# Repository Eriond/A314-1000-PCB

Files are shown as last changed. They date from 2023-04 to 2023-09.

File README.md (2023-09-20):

# A314-1000-PCB
A314 board for the A1000's front memory expansion bay

<p>This is the Amiga 1000 version of [the A314](https://github.com/niklasekstrom/a314), designed to fit in the front expansion bay of the iconic computer.<br>
It is built using readily available components and has been designed with the DIY builder in mind (ie. no BGA chips, and reasonably large components with external leads)</p>
<p>It is a 1:1 replacement for the A1050 C= memory expansion, and will provide 256kB of chipRAM regardless if the RPiZ module is present.<br>
The board has room for an optional RTC chip which can provide time and date to the RPiZ via an I2C bus. This bus has also been made available via solderpads and is accessible from both sides of the PCB. It can be useful if you'd like to add other peripherals, like RGB lights or an OLED display for instance.</p>

For more information on how to bring this hardware to life, please check out Niklas repository at [https://github.com/niklasekstrom/a314-1000-gateware](https://github.com/niklasekstrom/a314-1000-gateware)

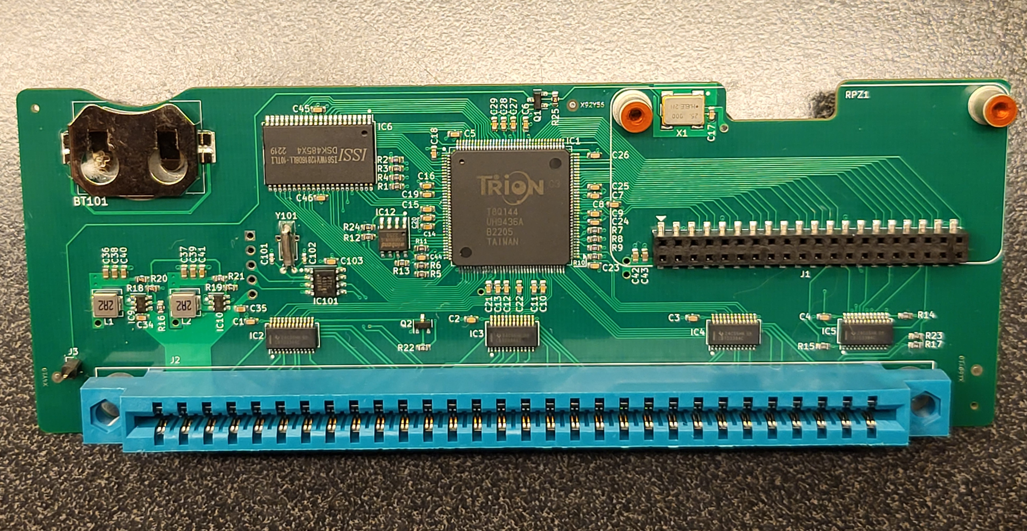
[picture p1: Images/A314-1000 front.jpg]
PCB


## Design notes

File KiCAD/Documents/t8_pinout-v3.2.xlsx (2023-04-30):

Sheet: T8F49
© 2020 |  |  | v13
Bank Number | Pin Name | Configuration Function | FBGA49
- | VCC |  | C4
- | VCC |  | D5
- | VCC |  | -
- | VCC |  | -
- | VCC |  | -
- | GND |  | A2 | Legend
- | GND |  | A6 |  | Bank 1A pins
- | GND |  | B1 |  | Bank 1B pins
- | GND |  | C1 |  | Bank 1C pins
- | GND |  | C5 |  | Bank 2A pins
- | GND |  | D4 |  | bank 2B pins
- | GND |  | E7
- | GND |  | -
- | GND |  | -
- | GND |  | -
BANK1A | CDONE | CDONE | F4
BANK1A | CRESET_N | CRESET_N | G4
BANK1A | GPIOL_00 |  | -
BANK1A | GPIOL_01_SS_N | SS_N | G3
BANK1A | GPIOL_02_CCK | CCK | F3
BANK1A | GPIOL_03_CDI4 | CDI4 | G2
BANK1A | GPIOL_04_CDI0 | CDI0 | F2
BANK1A | GPIOL_05_CDI5 | CDI5 | G1
BANK1A | GPIOL_06_CDI1 | CDI1 | F1
BANK1A | GPIOL_07_CDI6 | CDI6 | E3
BANK1A | GPIOL_08 |  | -
BANK1A | GPIOL_09_CDI2 | CDI2 | E2
BANK1A | GPIOL_10_CDI7 | CDI7 | E1
BANK1A | GPIOL_11_CDI3 | CDI3 | D2
BANK1A | GPIOL_12_CTRL0 |  | C2
BANK1A | GPIOL_13_CTRL1 |  | D3
BANK1A | GPIOL_14_CLK0 |  | C3
BANK1A | GPIOL_15_CLK1 |  | -
BANK1A | VCCIO1A |  | D1
BANK1B | GPIOL_16_CLK2 |  | B3
BANK1B | GPIOL_17_CLK3 |  | -
BANK1B | GPIOL_18_CTRL2 |  | A3
BANK1B | GPIOL_19_CTRL3 |  | -
BANK1B | GPIOL_20_PLLIN |  | B4
BANK1B | GPIOL_21_NSTATUS | NSTATUS | A4
BANK1B | TCK |  | -
BANK1B | TDI |  | -
BANK1B | TDO |  | -
BANK1B | TMS |  | -
BANK1B | VCCIO1B |  | B2
BANK1C | VCCA_PLL |  | A1
BANK2A | GPIOR_00 |  | -
BANK2A | GPIOR_01 |  | -
BANK2A | GPIOR_02_RESERVED_OUT | RESERVED_OUT | B5
BANK2A | GPIOR_03 |  | -
BANK2A | GPIOR_04 |  | -
BANK2A | GPIOR_05 |  | A5
BANK2A | GPIOR_06 |  | -
BANK2A | GPIOR_07 |  | A7
BANK2A | GPIOR_08 |  | -
BANK2A | GPIOR_09 |  | -
BANK2A | GPIOR_10 |  | B7
BANK2A | GPIOR_11 |  | -
BANK2A | GPIOR_12 |  | -
BANK2A | GPIOR_13 |  | C6
BANK2A | GPIOR_14 |  | -
BANK2A | GPIOR_15_CBUS0 | CBUS0 | D6
BANK2A | GPIOR_16_CTRL7_CBUS1 | CBUS1 | C7
BANK2A | GPIOR_17_CTRL6_CBUS2 | CBUS2 | D7
BANK2A | GPIOR_18_CLK7 |  | -
BANK2A | GPIOR_19_CLK6 |  | E6
BANK2A | VCCIO2A |  | B6
BANK2B | GPIOR_20_CLK5 |  | -
BANK2B | GPIOR_21_CLK4_CBSEL1 | CBSEL1 | E4
BANK2B | GPIOR_22_CTRL5 |  | -
BANK2B | GPIOR_23_CTRL4 |  | E5
BANK2B | GPIOR_24 |  | F5
BANK2B | GPIOR_25 |  | -
BANK2B | GPIOR_26_CBSEL0 | CBSEL0 | F6
BANK2B | GPIOR_27 |  | -
BANK2B | GPIOR_28 |  | -
BANK2B | GPIOR_29 |  | -
BANK2B | GPIOR_30 |  | -
BANK2B | GPIOR_31 |  | -
BANK2B | GPIOR_32 |  | -
BANK2B | GPIOR_34_CSI | CSI | G5
BANK2B | GPIOR_35_CSO | CSO | G6
BANK2B | GPIOR_36 |  | -
BANK2B | GPIOR_37_TEST_N | TEST_N | G7
BANK2B | VCCIO2B |  | F7

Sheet: T8F81
© 2020 |  |  | v13
Bank Number | Pin Name | Configuration Function | FBGA81
- | VCC |  | D4
- | VCC |  | E5
- | VCC |  | F2
- | VCC |  | F9
- | VCC |  | C1
- | GND |  | A2 | Legend
- | GND |  | B1 |  | Bank 1A pins
- | GND |  | B7 |  | Bank 1B pins
- | GND |  | D1 |  | Bank 1C pins
- | GND |  | D5 |  | Bank 2A pins
- | GND |  | E4 |  | bank 2B pins
- | GND |  | E9
- | GND |  | G2
- | GND |  | G7
- | GND |  | H1
BANK1A | CDONE | CDONE | H5
BANK1A | CRESET_N | CRESET_N | J5
BANK1A | GPIOL_00 |  | G5
BANK1A | GPIOL_01_SS_N | SS_N | J4
BANK1A | GPIOL_02_CCK | CCK | H4
BANK1A | GPIOL_03_CDI4 | CDI4 | G4
BANK1A | GPIOL_04_CDI0 | CDI0 | F4
BANK1A | GPIOL_05_CDI5 | CDI5 | J3
BANK1A | GPIOL_06_CDI1 | CDI1 | H3
BANK1A | GPIOL_07_CDI6 | CDI6 | G3
BANK1A | GPIOL_08 |  | -
BANK1A | GPIOL_09_CDI2 | CDI2 | J2
BANK1A | GPIOL_10_CDI7 | CDI7 | H2
BANK1A | GPIOL_11_CDI3 | CDI3 | F3
BANK1A | GPIOL_12_CTRL0 |  | G1
BANK1A | GPIOL_13_CTRL1 |  | F1
BANK1A | GPIOL_14_CLK0 |  | E2
BANK1A | GPIOL_15_CLK1 |  | E1
BANK1A | VCCIO1A |  | J1
BANK1B | GPIOL_16_CLK2 |  | C2
BANK1B | GPIOL_17_CLK3 |  | D2
BANK1B | GPIOL_18_CTRL2 |  | E3
BANK1B | GPIOL_19_CTRL3 |  | D3
BANK1B | GPIOL_20_PLLIN |  | C3
BANK1B | GPIOL_21_NSTATUS | NSTATUS | B3
BANK1B | TCK |  | C4
BANK1B | TDI |  | A3
BANK1B | TDO |  | A4
BANK1B | TMS |  | B4
BANK1B | VCCIO1B |  | B2
BANK1C | VCCA_PLL |  | A1
BANK2A | GPIOR_00 |  | A5
BANK2A | GPIOR_01 |  | B5
BANK2A | GPIOR_02_RESERVED_OUT | RESERVED_OUT | C5
BANK2A | GPIOR_03 |  | A6
BANK2A | GPIOR_04 |  | -
BANK2A | GPIOR_05 |  | B6
BANK2A | GPIOR_06 |  | C6
BANK2A | GPIOR_07 |  | C7
BANK2A | GPIOR_08 |  | A8
BANK2A | GPIOR_09 |  | -
BANK2A | GPIOR_10 |  | A9
BANK2A | GPIOR_11 |  | B8
BANK2A | GPIOR_12 |  | C8
BANK2A | GPIOR_13 |  | D6
BANK2A | GPIOR_14 |  | B9
BANK2A | GPIOR_15_CBUS0 | CBUS0 | C9
BANK2A | GPIOR_16_CTRL7_CBUS1 | CBUS1 | D7
BANK2A | GPIOR_17_CTRL6_CBUS2 | CBUS2 | D8
BANK2A | GPIOR_18_CLK7 |  | D9
BANK2A | GPIOR_19_CLK6 |  | E8
BANK2A | VCCIO2A |  | A7
BANK2B | GPIOR_20_CLK5 |  | F8
BANK2B | GPIOR_21_CLK4_CBSEL1 | CBSEL1 | E7
BANK2B | GPIOR_22_CTRL5 |  | F7
BANK2B | GPIOR_23_CTRL4 |  | E6
BANK2B | GPIOR_24 |  | F6
BANK2B | GPIOR_25 |  | F5
BANK2B | GPIOR_26_CBSEL0 | CBSEL0 | G9
BANK2B | GPIOR_27 |  | H9
BANK2B | GPIOR_28 |  | J9
BANK2B | GPIOR_29 |  | -
BANK2B | GPIOR_30 |  | J8
BANK2B | GPIOR_31 |  | G8
BANK2B | GPIOR_32 |  | H8
BANK2B | GPIOR_34_CSI | CSI | J7
BANK2B | GPIOR_35_CSO | CSO | G6
BANK2B | GPIOR_36 |  | H6
BANK2B | GPIOR_37_TEST_N | TEST_N | J6
BANK2B | VCCIO2B |  | H7

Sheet: T8Q144
© 2020 |  | v23
Bank Number | Pin Names | Configuration Functions | LVDS TX/RX Pairs | DDIO | LQFP144
- | GND |  |  |  | 1
- | VCCA_TL |  |  |  | 2
BANK1D | GPIOL_53_CDI10 | CDI10 |  | Yes | 3
BANK1D | GPIOL_54_CDI11 | CDI11 |  | Yes | 4 | Legend
- | GND |  |  |  | 5 |  | Bank 1A pins
BANK1D | GPIOL_46 |  |  | Yes | 6 |  | Bank 1B pins
BANK1C | GPIOL_41_CDI9 | CDI9 |  | Yes | 7 |  | Bank 1C pins
BANK1C | GPIOL_40_CDI8 | CDI8 |  | Yes | 8 |  | Bank 1D pins
- | GND |  |  |  | 9 |  | Bank 1E pins
BANK1C | GPIOL_32_CTRL4_CDI7 | CDI7 |  | Yes | 10 |  | Bank 3A pins
BANK1C | GPIOL_31_CLK7_CDI6 | CDI6 |  | Yes | 11 |  | Bank 3B pins
- | VCCIO1C_1D |  |  |  | 12 |  | Bank 3C pins
- | VCC |  |  |  | 13 |  | Bank 3D pins
BANK1B | GPIOL_25_CLK1 |  |  | Yes | 14 |  | Bank 3E pins
BANK1B | GPIOL_24_CLK0 |  |  | Yes | 15 |  | Bank 4A pins
BANK1B | GPIOL_22_CTRL2 |  |  | Yes | 16 |  | Bank 4B pins
BANK1B | GPIOL_21_CTRL1_CDI5 | CDI5 |  | Yes | 17
BANK1B | GPIOL_20_CTRL0_CDI4 | CDI4 |  | Yes | 18
BANK1B | GPIOL_13_CDI3 | CDI3 |  | Yes | 19 | Note: | In the Legend, banks with the same color have their power shorted in the package
BANK1B | GPIOL_12_CDI2 | CDI2 |  | Yes | 20 |  | For example, VCCIO1C_1D shorts the power of bank 1C and 1D together
- | VCCIO1B |  |  |  | 21
- | VCC |  |  |  | 22
- | VCCIO1A |  |  |  | 23
BANK1A | TDO | TDO |  |  | 24
BANK1A | TMS | TMS |  |  | 25
BANK1A | TCK | TCK |  |  | 26
BANK1A | TDI | TDI |  |  | 27
BANK1A | GPIOL_09_CDI1 | CDI1 |  |  | 28
BANK1A | GPIOL_08_CDI0 | CDI0 |  |  | 29
BANK1A | GPIOL_01_CCK | CCK |  |  | 30
BANK1A | GPIOL_00_SS_N | SS_N |  |  | 31
BANK1A | GPIOL_04_CSI | CSI |  |  | 32
BANK1A | GPIOL_05_CSO | CSO |  |  | 33
BANK1A | CDONE |  |  |  | 34
BANK1A | CRESET_N |  |  |  | 35
BANK4B | REF_RES |  |  |  | 36
- | GND |  |  |  | 37
BANK4B | GPIOB_TXP00 |  | GPIOB_TX00 |  | 38
BANK4B | GPIOB_TXN00 |  | GPIOB_TX00 |  | 39
BANK4B | GPIOB_TXP02 |  | GPIOB_TX02 |  | 40
BANK4B | GPIOB_TXN02 |  | GPIOB_TX02 |  | 41
BANK4B | GPIOB_TXP04 |  | GPIOB_TX04 |  | 42
BANK4B | GPIOB_TXN04 |  | GPIOB_TX04 |  | 43
- | GND |  |  |  | 44
BANK4B | GPIOB_TXP06 |  | GPIOB_TX06 |  | 45
BANK4B | GPIOB_TXN06 |  | GPIOB_TX06 |  | 46
BANK4B | GPIOB_TXP09 |  | GPIOB_TX09 |  | 47
BANK4B | GPIOB_TXN09 |  | GPIOB_TX09 |  | 48
- | VCC |  |  |  | 49
- | GND |  |  |  | 50
- | VCCIO4B |  |  |  | 51
- | VCCIO4B |  |  |  | 52
BANK4B | GPIOB_TXP11 |  | GPIOB_TX11 |  | 53
BANK4B | GPIOB_TXN11 |  | GPIOB_TX11 |  | 54
BANK4A | GPIOB_RXP00 |  | GPIOB_RX00 |  | 55
BANK4A | GPIOB_RXN00 |  | GPIOB_RX00 |  | 56
- | VCC |  |  |  | 57
BANK4A | GPIOB_RXP02 |  | GPIOB_RX02 |  | 58
BANK4A | GPIOB_RXN02 |  | GPIOB_RX02 |  | 59
BANK4A | GPIOB_RXN03 |  | GPIOB_RX03 |  | 60
BANK4A | GPIOB_RXP03 |  | GPIOB_RX03 |  | 61
- | VCCIO4A |  |  |  | 62
- | VCCIO4A |  |  |  | 63
- | GND |  |  |  | 64
BANK4A | GPIOB_RXN07 |  | GPIOB_RX07 |  | 65
BANK4A | GPIOB_RXP07 |  | GPIOB_RX07 |  | 66
BANK4A | GPIOB_RXP10 |  | GPIOB_RX10 |  | 67
BANK4A | GPIOB_RXN10 |  | GPIOB_RX10 |  | 68
BANK4A | GPIOB_RXN12_EXTFB0 |  | GPIOB_RX12 |  | 69
BANK4A | GPIOB_RXP12_EXTFB0 |  | GPIOB_RX12 |  | 70
BANK4A | GPIOB_CLKP0 |  | GPIOB_CLK0 |  | 71
BANK4A | GPIOB_CLKN0 |  | GPIOB_CLK0 |  | 72
- | VCCA_BR |  |  |  | 73
BANK3E | GPIOR_158_TEST_N | TEST_N |  | Yes | 74
BANK3E | GPIOR_157_PLLIN |  |  | Yes | 75
BANK3E | GPIOR_155 |  |  | Yes | 76
BANK3E | GPIOR_154 |  |  | Yes | 77
BANK3E | GPIOR_151_CBUS0 | CBUS0 |  | Yes | 78
BANK3E | GPIOR_150_CBUS1 | CBUS1 |  | Yes | 79
BANK3E | GPIOR_149_CBUS2 | CBUS2 |  | Yes | 80
BANK3D | GPIOR_139 |  |  | Yes | 81
BANK3D | GPIOR_138 |  |  | Yes | 82
BANK3D | GPIOR_136_CDI16 | CDI16 |  | Yes | 83
BANK3D | GPIOR_135_CDI17 | CDI17 |  | Yes | 84
- | VCC |  |  |  | 85
BANK3D | GPIOR_133_CDI18 | CDI18 |  | Yes | 86
BANK3D | GPIOR_132_CDI19 | CDI19 |  | Yes | 87
- | VCCIO3E |  |  |  | 88
BANK3D | GPIOR_129_CTRL10 |  |  | Yes | 89
BANK3D | GPIOR_128_CTRL11 |  |  | Yes | 90
- | VCCIO3D |  |  |  | 91
BANK3D | GPIOR_125_CLK10 |  |  | Yes | 92
BANK3C | GPIOR_123_CLK12_CDI20 | CDI20 |  | Yes | 93
- | GND |  |  |  | 94
- | VCCIO3B_3C |  |  |  | 95
- | VCC |  |  |  | 96
BANK3C | GPIOR_122_CLK13_CDI21 | CDI21 |  | Yes | 97
BANK3C | GPIOR_117_CTRL14 |  |  | Yes | 98
BANK3C | GPIOR_116_CTRL15 |  |  | Yes | 99
BANK3C | GPIOR_113_CDI22 | CDI22 |  | Yes | 100
BANK3C | GPIOR_112_CDI23 | CDI23 |  | Yes | 101
BANK3B | GPIOR_105_CDI24 | CDI24 |  | Yes | 102
BANK3B | GPIOR_104_CDI25 | CDI25 |  | Yes | 103
- | GND |  |  |  | 104
BANK3B | GPIOR_95_CDI26 | CDI26 |  | Yes | 105
BANK3B | GPIOR_94_CDI27 | CDI27 |  | Yes | 106
- | VCCA_TR |  |  |  | 107
- | GND |  |  |  | 108
BANK3A | GPIOR_88_CDI28 | CDI28 |  |  | 109
BANK3A | GPIOR_87_CDI29 | CDI29 |  |  | 110
BANK3A | GPIOR_85 |  |  |  | 111
BANK3A | GPIOR_86 |  |  |  | 112
BANK3A | GPIOR_84 |  |  |  | 113
BANK3A | GPIOR_83 |  |  |  | 114
BANK3A | GPIOR_82 |  |  |  | 115
BANK3A | GPIOR_81_MREFCLK |  |  |  | 116
BANK3A | GPIOR_80 |  |  |  | 117
BANK3A | GPIOR_79_EXTFB1_CDI30 | CDI30 |  |  | 118
BANK3A | GPIOR_78_EXTFB0_CDI31 | CDI31 |  |  | 119
- | GND |  |  |  | 120
- | GND |  |  |  | 121
- | VCCIO3A |  |  |  | 122
BANK3A | GPIOR_77_PLLIN1 | CBSEL1 |  |  | 123
BANK3A | GPIOR_76_PLLIN0 | CBSEL0 |  |  | 124
- | VCC |  |  |  | 125
- | GND |  |  |  | 126
- | GND |  |  |  | 127
- | VCC |  |  |  | 128
- | GND |  |  |  | 129
- | VCC |  |  |  | 130
BANK1E | GPIOL_75_PLLIN1 |  |  |  | 131
BANK1E | GPIOL_74_PLLIN0 |  |  |  | 132
- | GND |  |  |  | 133
BANK1E | GPIOL_73_EXTFB1_CDI15 | CDI15 |  |  | 134
BANK1E | GPIOL_72_EXTFB0_CDI14 | CDI14 |  |  | 135
BANK1E | GPIOL_71_NSTATUS | NSTATUS |  |  | 136
BANK1E | GPIOL_70_CBSEL0 | CBSEL0 |  |  | 137
BANK1E | GPIOL_69_CBSEL1 | CBSEL1 |  |  | 138
BANK1E | GPIOL_68 |  |  |  | 139
BANK1E | GPIOL_67_CDI13 | CDI13 |  |  | 140
BANK1E | GPIOL_65 |  |  |  | 141
BANK1E | GPIOL_66_CDI12 | CDI12 |  |  | 142
- | VCCIO1E |  |  |  | 143
BANK1E | GPIOL_64 |  |  |  | 144

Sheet: Revision History
Revision History
Date | Document Revision | Package | Remarks
2018-06-01 | 1.0 | BGA49, BGA81 | Initial release
2019-08-22 | 2.0 | QFP144 | Initial preliminary release
 |  | BGA49, BGA81 | Rename GPIOR_37_TESTN as GPIOR_37_TEST_N and CONDONE as CDONE to align with Efinity naming
2020-04-08 | 3.0 | QFP144 | Production release
2020-08-20 | 3.1 | All | Removed Trion T4 pinout Separated pinout for package BGA49 and BGA81 in different sheets
2022-01-07 | 3.2 | QFP144 | Rename LVDS TX/RX pairs to align with the Efinity software

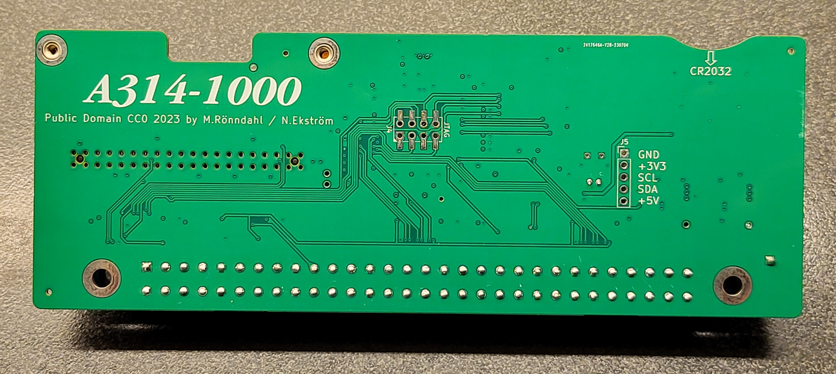
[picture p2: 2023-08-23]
Images/A314-1000 back.jpg

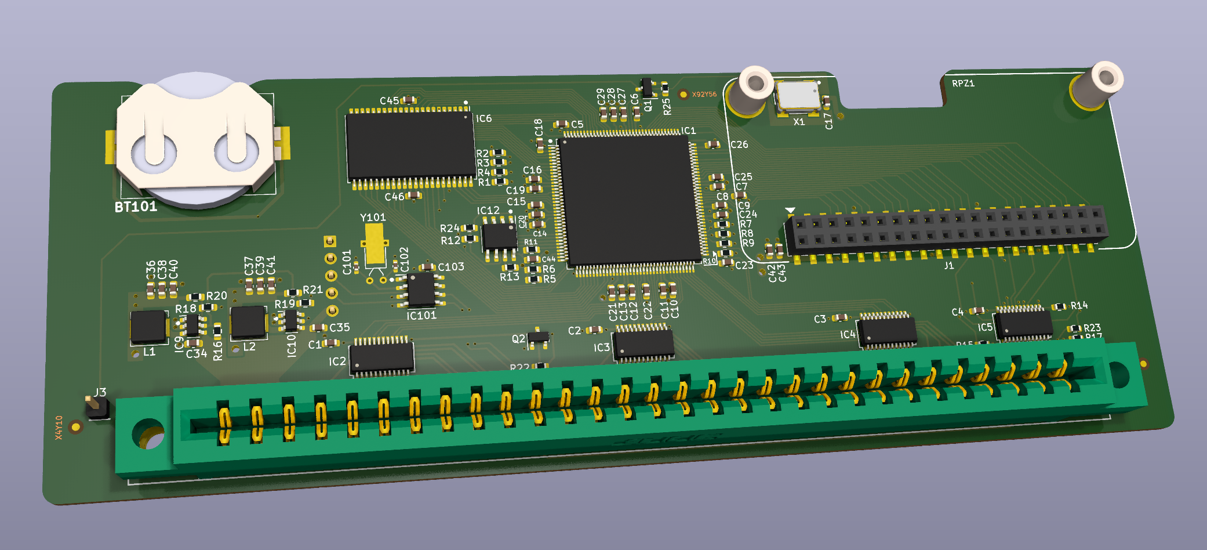
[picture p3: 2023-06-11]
Images/PCB.png

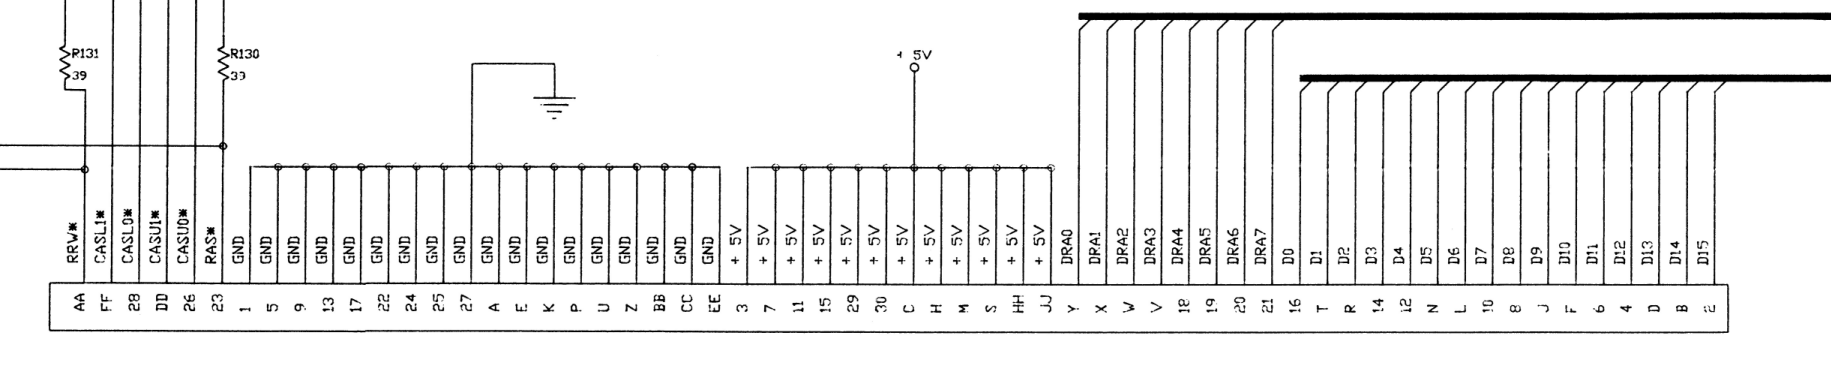
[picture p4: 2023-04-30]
KiCAD/Documents/A1000 DRAM exp port.png

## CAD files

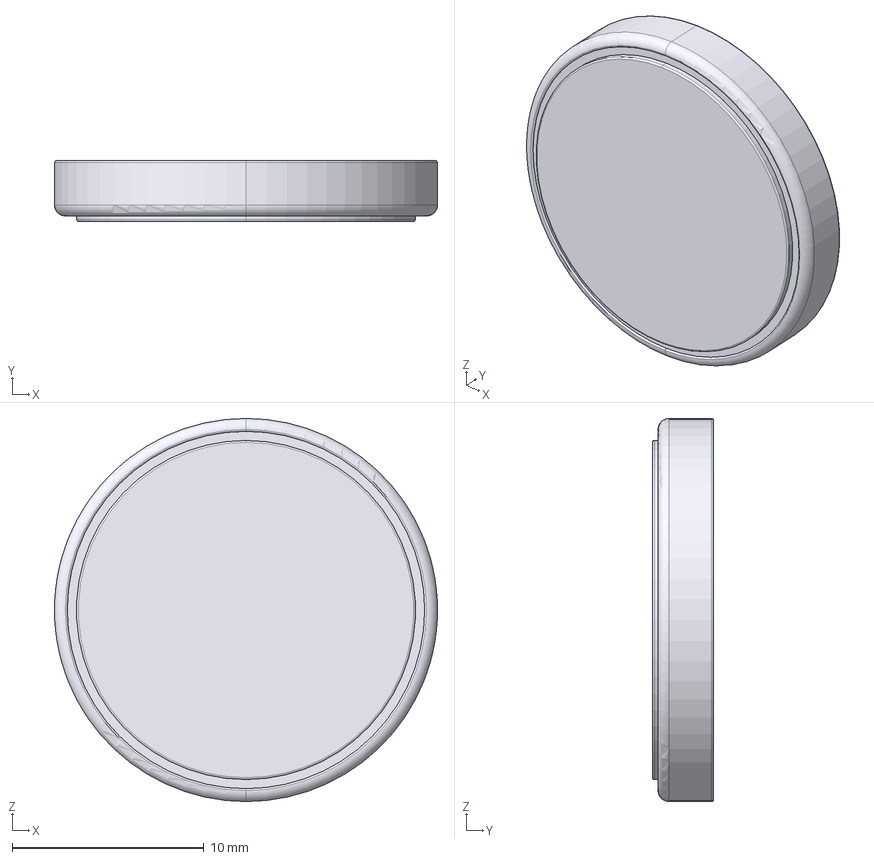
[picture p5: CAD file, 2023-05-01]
KiCAD/3D models/CR2032 battery.stp
20.0 x 3.20 x 20.0 mm

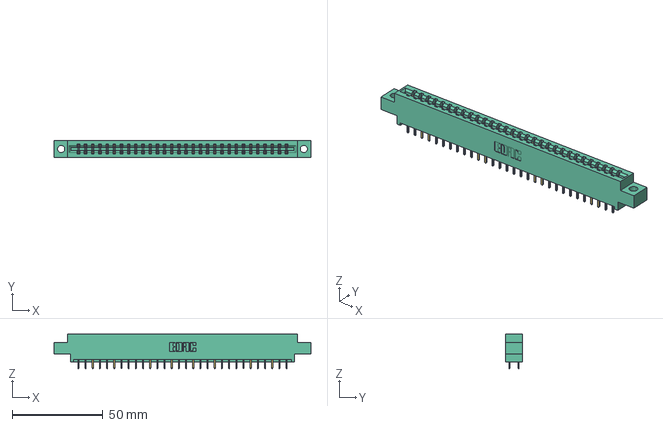
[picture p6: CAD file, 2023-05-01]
KiCAD/3D models/337-060-521-804 - EDAC Card Edge Connector.stp
141.9 x 9.40 x 19.1 mm
337 Part_0.170 Offset - 0.156 Dia-TH

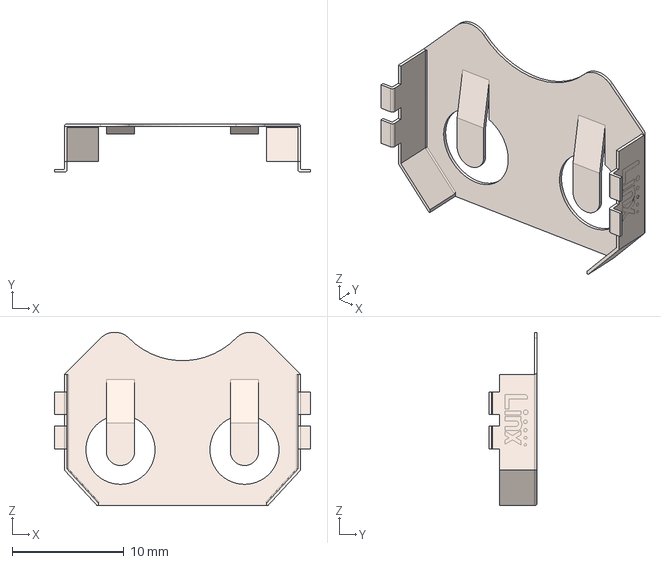
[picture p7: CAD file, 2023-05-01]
KiCAD/3D models/BAT-HLD-001.stp
22.9 x 4.32 x 15.5 mm

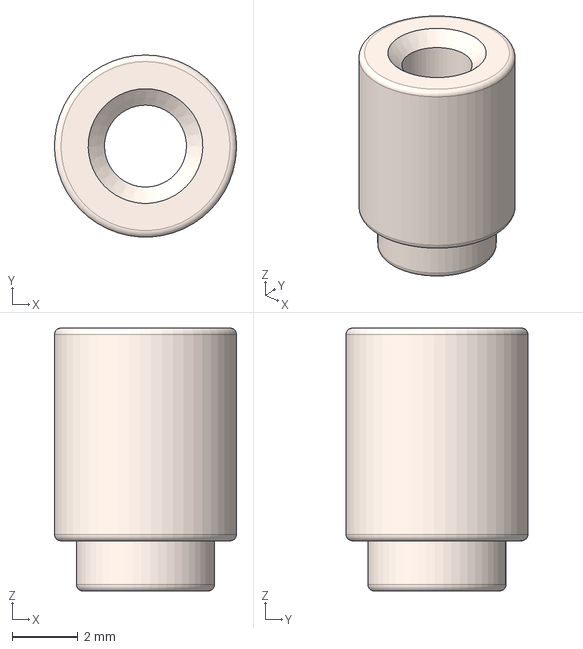
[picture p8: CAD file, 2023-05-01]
KiCAD/3D models/SMTSOM2.565BTR.stp
5.56 x 5.55 x 8.03 mm

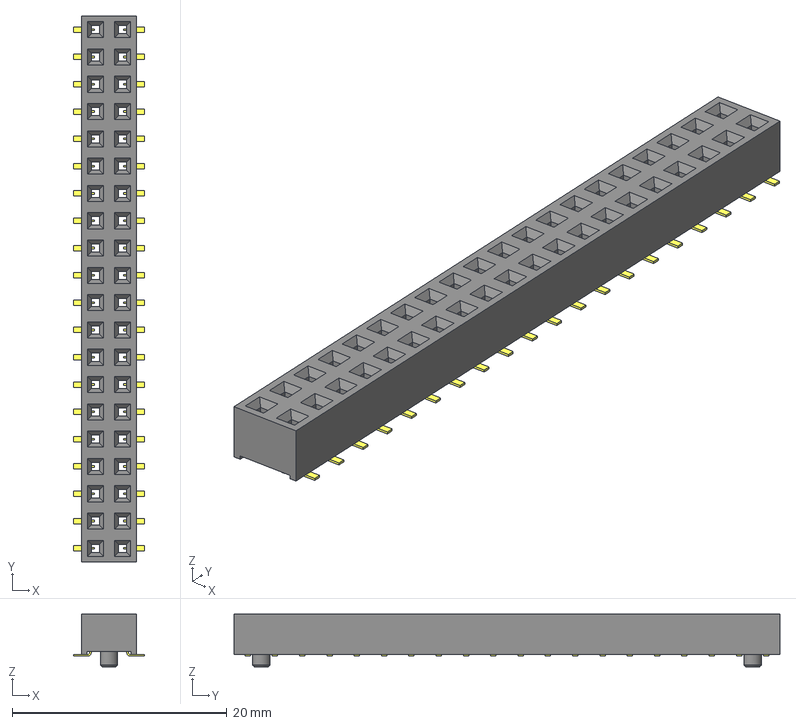
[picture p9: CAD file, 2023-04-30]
KiCAD/3D models/LianSheng FH-00339.stp
6.58 x 50.8 x 4.90 mm
HLE-120-02-DV_socket
C-132-12-20-DV

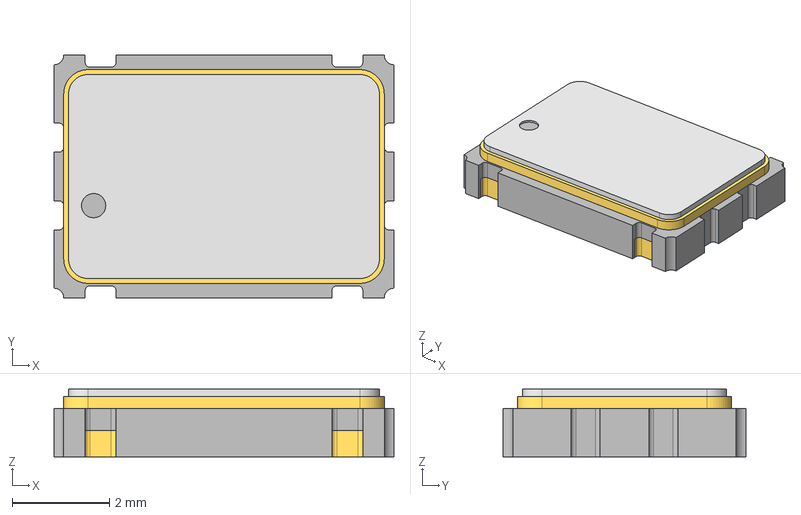
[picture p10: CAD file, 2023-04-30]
KiCAD/3D models/HSO751S.stp
7.00 x 5.00 x 1.40 mm
Pins
Top
Lid

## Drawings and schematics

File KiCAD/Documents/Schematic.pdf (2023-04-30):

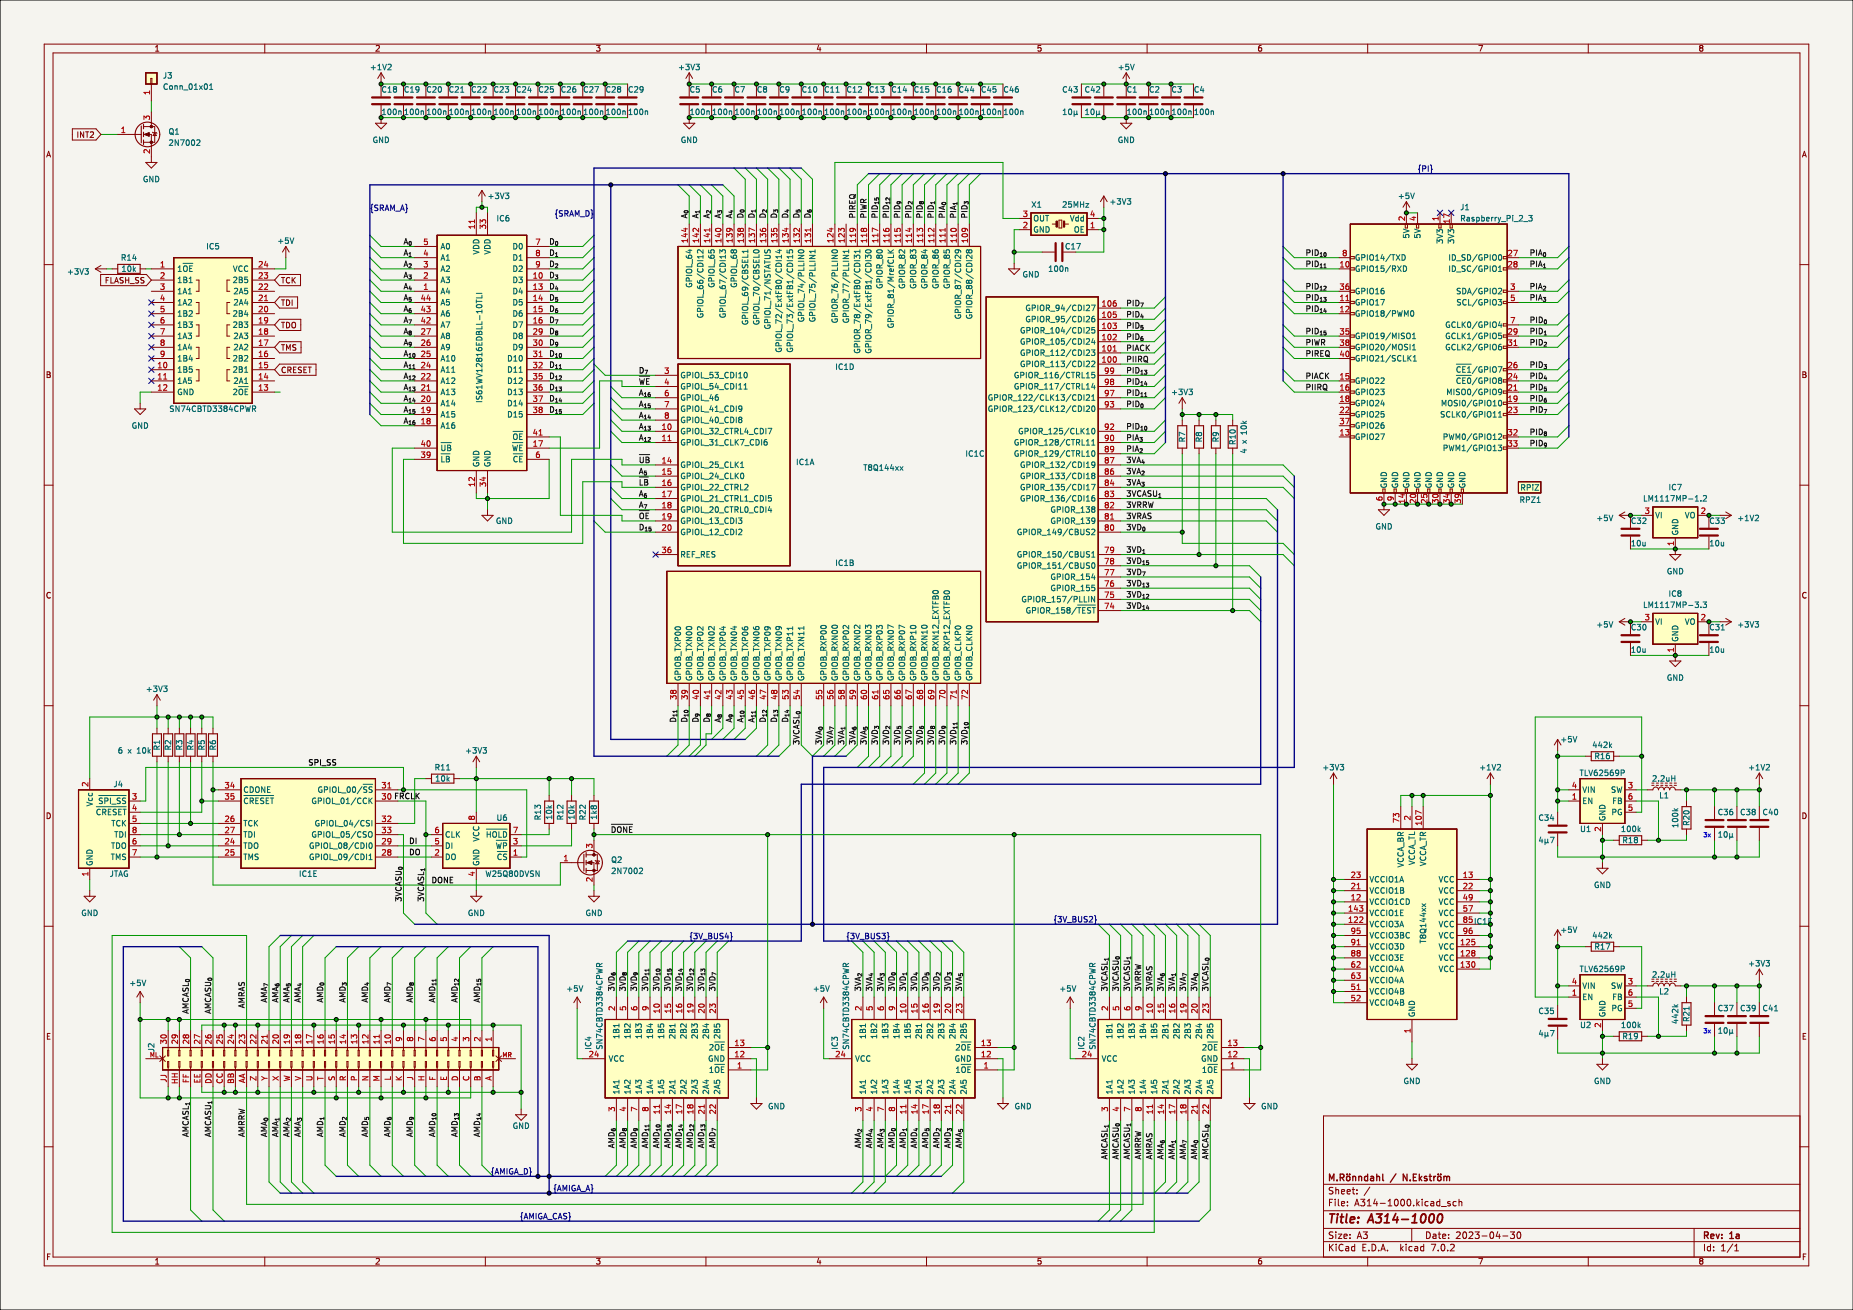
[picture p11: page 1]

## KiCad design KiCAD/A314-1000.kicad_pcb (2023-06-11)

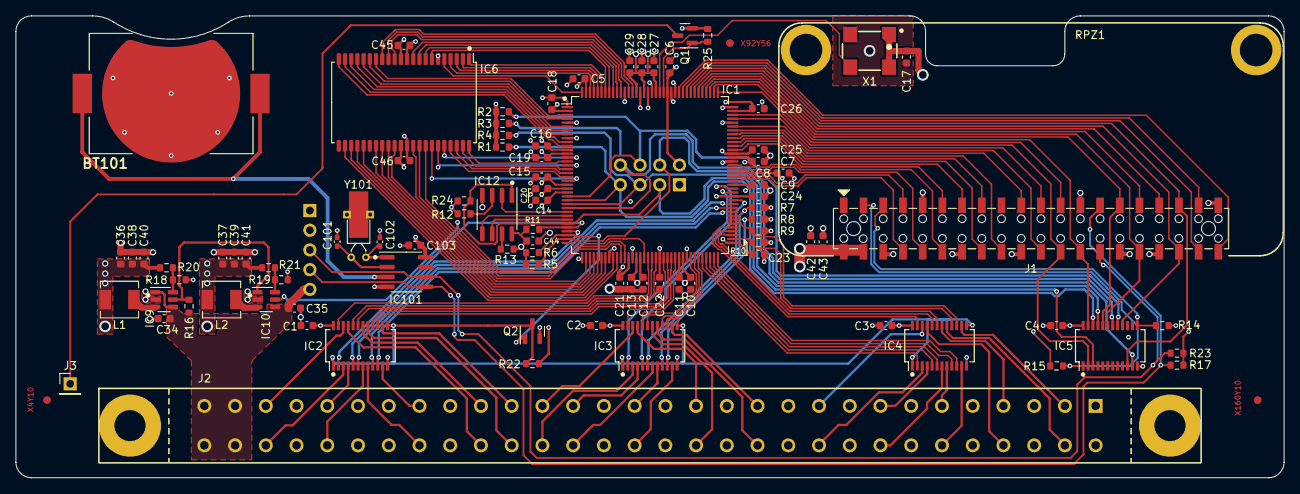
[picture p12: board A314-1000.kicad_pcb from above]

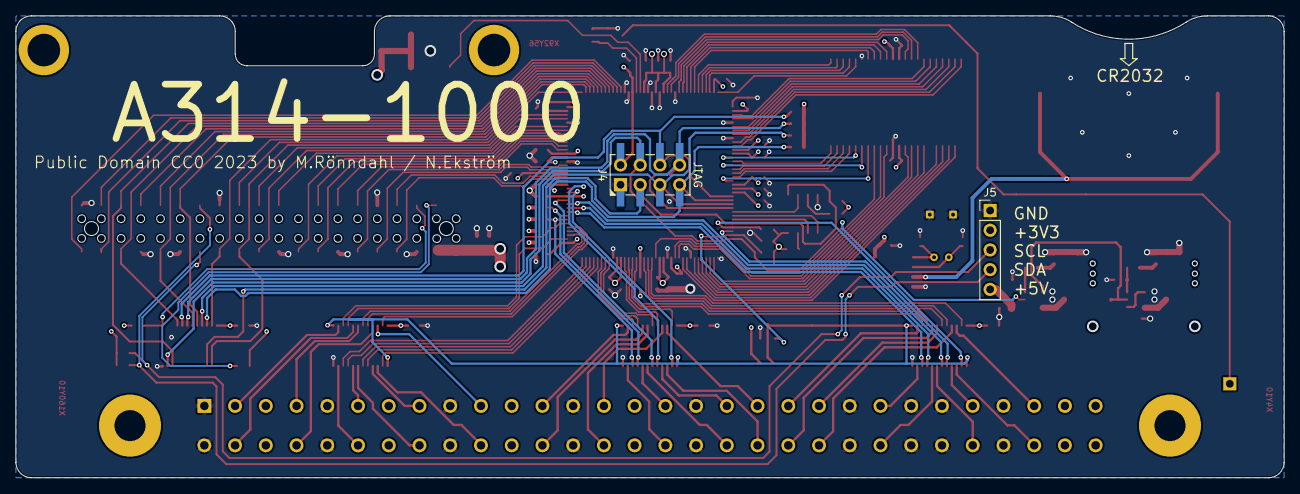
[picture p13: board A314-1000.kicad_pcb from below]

Board: 4 copper layers, 163.4 x 59.5 mm, 98 parts (2 on the bottom side), 153 nets.

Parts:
BT101: CR2032; BATHLD001
C1, C2, C3, C4, C5, C6, C7, C8, C9, C10, C11, C12, C13, C14, C15, C16, C17, C18, C19, C20, C21, C22, C23, C24, C25, C26, C27, C28, C29, C44, C45, C46, C103: 100n; C_0603_1608Metric
C34, C35: 4µ7; C_0603_1608Metric
C36, C37, C38, C39, C40, C41, C42, C43: 10µ; C_0603_1608Metric
C101, C102: 8p; C_0402_1005Metric_Pad0.74x0.62mm_HandSolder
FID1, FID2, FID3: Fiducial; Fiducial_1mm_Mask2mm
H1, H2: MountingHole; M2.5_Mount
IC1: T8Q144xx; LQFP-144_20x20mm_P0.5mm
IC2, IC3, IC4, IC5: SN74CBTD3384CPWR; SSOP-24_3.9x8.7mm_P0.635mm
IC6: IS61WV12816EDBLL-10TLI; TSOP-II-44_10.16x18.41mm_P0.8mm
IC9, IC10: TLV62569P; SOT-23-6
IC12: W25Q80DVSN; SOIC-8_3.9x4.9mm_P1.27mm
IC101: PT7C4311WEX; SOIC-8_3.9x4.9mm_P1.27mm
J1: Raspberry_Pi_2_3; LianSheng-FH-00339
J2: 2x30 Card edge conn.; 337-060-52x-804
J3: INT2; PinHeader_1x01_P2.54mm_Vertical
J4: JTAG; PinHeader_2x04_P2.54mm_Vertical_Multi
J5: RASP_I2C; PinHeader_1x05_P2.54mm_Vertical
L1, L2: 2.2uH; L_Sunlord_MWSA0402S
Q1, Q2: 2N7002; SOT-23
R1, R2, R3, R4, R5, R6, R7, R8, R9, R10, R11, R12, R13, R14, R15, R24: 10k; R_0603_1608Metric
R16, R21: 442k; R_0603_1608Metric
R17, R23, R25: 3k9; R_0603_1608Metric
R18, R19, R20: 100k; R_0603_1608Metric
R22: 1k8; R_0603_1608Metric
RPZ1: RPiZ; RPiZ mount
X1: 25MHz; HSO751S
Y101: 32.768kHz; Crystal_DS26_D2.0mm_L6.0mm_Horizontal_1EP_style2

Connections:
+1V2: C18.1, C19.1, C20.1, C21.1, C22.1, C23.1, C24.1, C25.1, C26.1, C27.1, C28.1, C29.1, C36.1, C38.1, C40.1, IC1.2 (VCCA_TL), IC1.13 (VCC), IC1.22 (VCC), IC1.49 (VCC), IC1.57 (VCC), IC1.73 (VCCA_BR), IC1.85 (VCC), IC1.96 (VCC), IC1.107 (VCCA_TR), IC1.125 (VCC), IC1.128 (VCC), IC1.130 (VCC), L1.2, R20.2
+3V3: C5.1, C6.1, C7.1, C8.1, C9.1, C10.1, C11.1, C12.1, C13.1, C14.1, C15.1, C16.1, C17.1, C37.1, C39.1, C41.1, C44.1, C45.1, C46.1, C103.1, IC1.12 (VCCIO1CD), IC1.21 (VCCIO1B), IC1.23 (VCCIO1A), IC1.51 (VCCIO4B), IC1.52 (VCCIO4B), IC1.62 (VCCIO4A), IC1.63 (VCCIO4A), IC1.88 (VCCIO3E), IC1.91 (VCCIO3D), IC1.95 (VCCIO3BC), IC1.122 (VCCIO3A), IC1.143 (VCCIO1E), IC6.11 (VDD), IC6.33 (VDD), IC12.8 (VCC), IC101.8 (V_{cc}), J4.2 (Vcc), J5.2, L2.2, R1.2, R2.2, R3.2, R4.2, R5.2, R6.2, R7.2, R8.2, R9.2, R10.2, R11.2, R12.1, R13.2, R14.2, R15.2, R17.2, R21.2, R22.2, R23.2, R24.2, X1.1 (OE), X1.4 (Vdd)
+5V: C1.1, C2.1, C3.1, C4.1, C34.1, C35.1, C42.1, C43.1, IC2.24 (VCC), IC3.24 (VCC), IC4.24 (VCC), IC5.24 (VCC), IC9.1 (EN), IC9.4 (VIN), IC10.4 (VIN), J1.2 (5V), J1.4 (5V), J2.3, J2.7, J2.11, J2.15, J2.29, J2.30, J2.C, J2.H, J2.HH, J2.JJ, J2.M, J2.S, J5.5, R16.2
/1V2PG: IC9.5 (PG), IC10.1 (EN), R16.1
/3VA_{0}: IC1.55 (GPIOB_RXP00), IC2.20 (2B4)
/3VA_{1}: IC1.58 (GPIOB_RXP02), IC2.16 (2B2)
/3VA_{2}: IC1.86 (GPIOR_133/CDI18), IC3.2 (1B1)
/3VA_{3}: IC1.84 (GPIOR_135/CDI17), IC3.6 (1B3)
/3VA_{4}: IC1.87 (GPIOR_132/CDI19), IC3.5 (1B2)
/3VA_{5}: IC1.60 (GPIOB_RXN03), IC3.23 (2B5)
/3VA_{6}: IC1.59 (GPIOB_RXN02), IC2.15 (2B1)
/3VA_{7}: IC1.56 (GPIOB_RXN00), IC2.19 (2B3)
/3VCASL_{0}: IC1.54 (GPIOB_TXN11), IC2.23 (2B5)
/3VCASL_{1}: IC1.32 (GPIOL_04/CSI), IC2.2 (1B1), R11.1
/3VCASU_{0}: IC1.33 (GPIOL_05/CSO), IC2.5 (1B2)
/3VCASU_{1}: IC1.83 (GPIOR_136/CDI16), IC2.6 (1B3)
/3VD_{0}: IC1.80 (GPIOR_149/CBUS2), IC3.9 (1B4), R7.1
/3VD_{1}: IC1.79 (GPIOR_150/CBUS1), IC3.10 (1B5), R8.1
/3VD_{2}: IC1.65 (GPIOB_RXN07), IC3.19 (2B3)
/3VD_{3}: IC1.61 (GPIOB_RXP03), IC3.20 (2B4)
/3VD_{4}: IC1.67 (GPIOB_RXP10), IC3.15 (2B1)
/3VD_{5}: IC1.66 (GPIOB_RXP07), IC3.16 (2B2)
/3VD_{6}: IC1.68 (GPIOB_RXN10), IC4.2 (1B1)
/3VD_{7}: IC1.77 (GPIOR_154), IC4.23 (2B5)
/3VD_{8}: IC1.69 (GPIOB_RXN12_EXTFB0), IC4.5 (1B2)
/3VD_{9}: IC1.70 (GPIOB_RXP12_EXTFB0), IC4.6 (1B3)
/3VD_{10}: IC1.72 (GPIOB_CLKN0), IC4.10 (1B5)
/3VD_{11}: IC1.71 (GPIOB_CLKP0), IC4.9 (1B4)
/3VD_{12}: IC1.75 (GPIOR_157/PLLIN), IC4.19 (2B3)
/3VD_{13}: IC1.76 (GPIOR_155), IC4.20 (2B4)
/3VD_{14}: IC1.74 (GPIOR_158/~TEST), IC4.16 (2B2), R10.1
/3VD_{15}: IC1.78 (GPIOR_151/CBUS0), IC4.15 (2B1), R9.1
/3VRAS: IC1.81 (GPIOR_139), IC2.10 (1B5)
/3VRRW: IC1.82 (GPIOR_138), IC2.9 (1B4)
/AMA_{0}: IC2.21 (2A4), J2.Y
/AMA_{1}: IC2.17 (2A2), J2.X
/AMA_{2}: IC3.3 (1A1), J2.W
/AMA_{3}: IC3.7 (1A3), J2.V
/AMA_{4}: IC3.4 (1A2), J2.18
/AMA_{5}: IC3.22 (2A5), J2.19
/AMA_{6}: IC2.14 (2A1), J2.20
/AMA_{7}: IC2.18 (2A3), J2.21
/AMCASL_{0}: IC2.22 (2A5), J2.28
/AMCASL_{1}: IC2.3 (1A1), J2.FF
/AMCASU_{0}: IC2.4 (1A2), J2.26
/AMCASU_{1}: IC2.7 (1A3), J2.DD
/AMD_{0}: IC3.8 (1A4), J2.16
/AMD_{1}: IC3.11 (1A5), J2.T
/AMD_{2}: IC3.18 (2A3), J2.R
/AMD_{3}: IC3.21 (2A4), J2.14
/AMD_{4}: IC3.14 (2A1), J2.12
/AMD_{5}: IC3.17 (2A2), J2.N
/AMD_{6}: IC4.3 (1A1), J2.L
/AMD_{7}: IC4.22 (2A5), J2.10
/AMD_{8}: IC4.4 (1A2), J2.8
/AMD_{9}: IC4.7 (1A3), J2.J
/AMD_{10}: IC4.11 (1A5), J2.F
/AMD_{11}: IC4.8 (1A4), J2.6
/AMD_{12}: IC4.18 (2A3), J2.4
/AMD_{13}: IC4.21 (2A4), J2.D
/AMD_{14}: IC4.17 (2A2), J2.B
/AMD_{15}: IC4.14 (2A1), J2.2
/AMRAS: IC2.11 (1A5), J2.23
/AMRRW: IC2.8 (1A4), J2.AA
/A_{0}: IC1.144 (GPIOL_64), IC6.5 (A0)
/A_{1}: IC1.142 (GPIOL_66/CDI12), IC6.4 (A1)
/A_{2}: IC1.141 (GPIOL_65), IC6.3 (A2)
/A_{3}: IC1.140 (GPIOL_67/CDI13), IC6.2 (A3)
/A_{4}: IC1.139 (GPIOL_68), IC6.1 (A4)
/A_{5}: IC1.15 (GPIOL_24_CLK0), IC6.44 (A5)
/A_{6}: IC1.17 (GPIOL_21_CTRL1_CDI5), IC6.43 (A6)
/A_{7}: IC1.18 (GPIOL_20_CTRL0_CDI4), IC6.42 (A7)
/A_{8}: IC1.42 (GPIOB_TXP04), IC6.27 (A8)
/A_{9}: IC1.43 (GPIOB_TXN04), IC6.26 (A9)
/A_{10}: IC1.45 (GPIOB_TXP06), IC6.25 (A10)
/A_{11}: IC1.46 (GPIOB_TXN06), IC6.24 (A11)
/A_{12}: IC1.11 (GPIOL_31_CLK7_CDI6), IC6.22 (A12)
/A_{13}: IC1.10 (GPIOL_32_CTRL4_CDI7), IC6.21 (A13)
/A_{14}: IC1.8 (GPIOL_40_CDI8), IC6.20 (A14)
/A_{15}: IC1.7 (GPIOL_41_CDI9), IC6.19 (A15)
/A_{16}: IC1.6 (GPIOL_46), IC6.18 (A16)
/DI: IC1.29 (GPIOL_08/CDI0), IC12.5 (DI)
/DO: IC1.28 (GPIOL_09/CDI1), IC12.2 (DO)
/DONE: IC1.34 (CDONE), Q2.1 (G), R6.1
/D_{0}: IC1.138 (GPIOL_69/CBSEL1), IC6.7 (D0)
/D_{1}: IC1.137 (GPIOL_70/CBSEL0), IC6.8 (D1)
/D_{2}: IC1.136 (GPIOL_71/NSTATUS), IC6.9 (D2)
/D_{3}: IC1.135 (GPIOL_72/ExtFB0/CDI14), IC6.10 (D3)
/D_{4}: IC1.134 (GPIOL_73/ExtFB1/CDI15), IC6.13 (D4)
/D_{5}: IC1.132 (GPIOL_74/PLLIN0), IC6.14 (D5)
/D_{6}: IC1.131 (GPIOL_75/PLLIN1), IC6.15 (D6)
/D_{7}: IC1.3 (GPIOL_53_CDI10), IC6.16 (D7)
/D_{8}: IC1.41 (GPIOB_TXN02), IC6.29 (D8)
/D_{9}: IC1.40 (GPIOB_TXP02), IC6.30 (D9)
/D_{10}: IC1.39 (GPIOB_TXN00), IC6.31 (D10)
/D_{11}: IC1.38 (GPIOB_TXP00), IC6.32 (D11)
/D_{12}: IC1.47 (GPIOB_TXP09), IC6.35 (D12)
/D_{13}: IC1.48 (GPIOB_TXN09), IC6.36 (D13)
/D_{14}: IC1.53 (GPIOB_TXP11), IC6.37 (D14)
/D_{15}: IC1.20 (GPIOL_12_CDI2), IC6.38 (D15)
/FRCLK: IC1.30 (GPIOL_01/CCK), IC12.6 (CLK)
/JTAG_OE_{0}: IC5.13 (2~OE), J1.5 (SCL/GPIO3), R14.1
/JTAG_OE_{1}: IC5.1 (1~OE), J1.3 (SDA/GPIO2), R15.1
/PIACK: IC1.100 (GPIOR_113/CDI22), J1.15 (GPIO22)
/PIA_{0}: IC1.101 (GPIOR_112/CDI23), J1.18 (GPIO24)
/PIA_{1}: IC1.103 (GPIOR_104/CDI25), J1.22 (GPIO25)
/PIA_{2}: IC1.118 (GPIOR_79/ExtFB1/CDI30), J1.37 (GPIO26)
/PIA_{3}: IC1.98 (GPIOR_117/CTRL14), J1.13 (GPIO27)
/PID_{0}: IC1.90 (GPIOR_128/CTRL11), J1.7 (GCLK0/GPIO4)
/PID_{1}: IC1.111 (GPIOR_85), IC5.20 (2B4), J1.29 (GCLK1/GPIO5)
/PID_{2}: IC1.113 (GPIOR_84), J1.31 (GCLK2/GPIO6)
/PID_{3}: IC1.110 (GPIOR_87/CDI29), IC5.23 (2B5), J1.26 (~CE1/GPIO7)
/PID_{4}: IC1.106 (GPIOR_94/CDI27), IC5.2 (1B1), J1.24 (~CE0/GPIO8)
/PID_{5}: IC1.105 (GPIOR_95/CDI26), J1.21 (MISO0/GPIO9)
/PID_{6}: IC1.102 (GPIOR_105/CDI24), J1.19 (MOSI0/GPIO10)
/PID_{7}: IC1.109 (GPIOR_88/CDI28), J1.23 (SCLK0/GPIO11)
/PID_{8}: IC1.112 (GPIOR_86), IC5.19 (2B3), J1.32 (PWM0/GPIO12)
/PID_{9}: IC1.114 (GPIOR_83), J1.33 (PWM1/GPIO13)
/PID_{10}: IC1.89 (GPIOR_129/CTRL10), J1.8 (GPIO14/TXD)
/PID_{11}: IC1.92 (GPIOR_125/CLK10), J1.10 (GPIO15/RXD)
/PID_{12}: IC1.115 (GPIOR_82), IC5.16 (2B2), J1.36 (GPIO16)
/PID_{13}: IC1.97 (GPIOR_122/CLK13/CDI21), J1.11 (GPIO17)
/PID_{14}: IC1.93 (GPIOR_123/CLK12/CDI20), J1.12 (GPIO18/PWM0)
/PID_{15}: IC1.116 (GPIOR_81/MrefCLK), IC5.10 (1B5), J1.35 (GPIO19/MISO1)
/PIIRQ: IC1.99 (GPIOR_116/CTRL15), J1.16 (GPIO23)
/PIREQ: IC1.119 (GPIOR_78/ExtFB0/CDI31), J1.40 (GPIO21/SCLK1)
/PIWR: IC1.117 (GPIOR_80), J1.38 (GPIO20/MOSI1)
/SCL: IC101.6 (SCL), J1.28 (ID_SC/GPIO1), J5.3, R23.1
/SDA: IC101.5 (SDA), J1.27 (ID_SD/GPIO0), J5.4, R17.1
/SPI_SS: IC1.31 (GPIOL_00/~SS), IC5.3 (1A1), IC12.1 (~CS), J4.3 (~SPI_SS), R24.1
/TCK: IC1.26 (TCK), IC5.21 (2A4), J4.5 (TCK), R4.1
/TDI: IC1.27 (TDI), IC5.18 (2A3), J4.8 (TDI), R3.1
/TDO: IC1.24 (TDO), IC5.17 (2A2), J4.6 (TDO), R2.1
/TMS: IC1.25 (TMS), IC5.22 (2A5), J4.7 (TMS), R1.1
/~CRESET: IC1.35 (~CRESET), IC5.11 (1A5), IC10.5 (PG), J4.4 (~CRESET), R5.1
/~DONE: IC2.1 (1~OE), IC2.13 (2~OE), IC3.1 (1~OE), IC3.13 (2~OE), IC4.1 (1~OE), IC4.13 (2~OE), Q2.3 (D), R22.1
/~LB: IC1.16 (GPIOL_22_CTRL2), IC6.39 (~LB)
/~OE: IC1.19 (GPIOL_13_CDI3), IC6.41 (~OE)
/~UB: IC1.14 (GPIOL_25_CLK1), IC6.40 (~UB)
/~WE: IC1.4 (GPIOL_54_CDI11), IC6.17 (~WE)
GND: BT101.2 (-), C1.2, C2.2, C3.2, C4.2, C5.2, C6.2, C7.2, C8.2, C9.2, C10.2, C11.2, C12.2, C13.2, C14.2, C15.2, C16.2, C17.2, C18.2, C19.2, C20.2, C21.2, C22.2, C23.2, C24.2, C25.2, C26.2, C27.2, C28.2, C29.2, C34.2, C35.2, C36.2, C37.2, C38.2, C39.2, C40.2, C41.2, C42.2, C43.2, C44.2, C45.2, C46.2, C101.2, C102.2, C103.2, IC1.1 (GND), IC1.5 (GND), IC1.9 (GND), IC1.37 (GND), IC1.44 (GND), IC1.50 (GND), IC1.64 (GND), IC1.94 (GND), IC1.104 (GND), IC1.108 (GND), IC1.120 (GND), IC1.121 (GND), IC1.126 (GND), IC1.127 (GND), IC1.129 (GND), IC1.133 (GND), IC2.12 (GND), IC3.12 (GND), IC4.12 (GND), IC5.12 (GND), IC6.6 (~CE), IC6.12 (GND), IC6.34 (GND), IC9.2 (GND), IC10.2 (GND), IC12.4 (GND), IC101.4 (GND), J1.6 (GND), J1.9 (GND), J1.14 (GND), J1.20 (GND), J1.25 (GND), J1.30 (GND), J1.34 (GND), J1.39 (GND), J2.1, J2.5 (Pin_55), J2.9, J2.13, J2.17, J2.22, J2.24, J2.25, J2.27, J2.A, J2.BB, J2.CC, J2.E, J2.EE, J2.K, J2.P, J2.U, J2.Z, J4.1 (GND), J5.1, Q1.2 (S), Q2.2 (S), R18.1, R19.1, R25.1, X1.2 (GND), Y101.3
unnamed: BT101.1 (+), IC101.3 (V_{bat})
unnamed: IC1.124 (GPIOR_76/PLLIN0), X1.3 (OUT)
unnamed: IC1.123 (GPIOR_77/PLLIN1), Q1.1 (G), R25.2
unnamed: IC9.6 (FB), R18.2, R20.1
unnamed: IC9.3 (SW), L1.1
unnamed: IC10.6 (FB), R19.2, R21.1
unnamed: IC10.3 (SW), L2.1
unnamed: IC12.7 (~HOLD), R13.1
unnamed: IC12.3 (~WP), R12.2
unnamed: C102.1, IC101.1 (X1), Y101.1
unnamed: C101.1, IC101.2 (X2), Y101.2
unnamed: J3.1, Q1.3 (D)

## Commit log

2023-04-30 Initial commit
    Work in Progress. Only for review, not complete.
    [337-060-521-804 - EDAC Card Edge Connector.stp, A314-1000.kicad_pcb, A314-1000.kicad_sch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]
2023-05-01 Ready for production?
    Board finished, added a RTC for the RPi. With a little luck and some production files, this may be ready for some PCBA :)
    [337-060-521-804 - EDAC Card Edge Connector.stp, A314-1000.kicad_pcb, A314-1000.kicad_sch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]
2023-05-03 Simplified PSU
    Enhanced battery replacement ergonomics
    [A314-1000.kicad_pcb, A314-1000.kicad_sch, PCB.dxf]
2023-05-03 Updated PCB image
2023-05-04 General cleanup
    Removed irrelevant files, addressed a number of DRC issues and cleaned up a footprint or two :)
    [A314-1000.kicad_pcb, JLCPCB_BOM.xls, PCB.dxf]
2023-06-11 First bug-ridded release
    This is the first non-alpha release. The hardware issues that were found in the alpha have been addressed. This board is now sent for a second production run.
    [A314-1000.kicad_pcb, A314-1000.kicad_sch]
2023-09-20 Update README.md
    The board is now in a mature, production-proven state. This update removes previous alpha- and beta-related comments.

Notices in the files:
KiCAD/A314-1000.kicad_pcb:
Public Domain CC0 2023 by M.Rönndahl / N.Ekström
